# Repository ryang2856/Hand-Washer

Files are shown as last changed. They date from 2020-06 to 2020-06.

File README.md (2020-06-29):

# Hand-Washer
The ESP8266 powered tutorial with a display to teach you how to wash your hands<br />	
Please check out my Arduino Project here: https://create.arduino.cc/projecthub/ryang2856/hand-washer-ed9280 <br />
<br />
The file structure is like this:
- 3D Printing Files {3D Printing STL files }
- Board Design (EasyEDA) {Easy EDA Source File with the GERBER.zip file}
- Code_NoClock {The code for the handwasher with NO clock}
- Code_Clock {The code for the handwasher with a clock}
- Schematic {The breadboard and PCB schematic in PDF Format}

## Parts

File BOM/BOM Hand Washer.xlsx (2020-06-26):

BOM Hand Washer
Merchant | Item | Cost | Website | Quantity
JLC PCB | Printed Circuit Boards | £3.24 | JLC PCB (https://jlcpcb.com/) | 5
Make It Quick LTD. | 3D Printed Front | £15.75 | Make It Quick (https://www.makeitquick.co.uk/) | 1
Make It Quick LTD. | 3D Printed Back | £8.30 | Make It Quick (https://www.makeitquick.co.uk/) | 1
Banggood | Display | £6.32 | Banggood Display (https://www.banggood.com/CP2102-ESP-12E-NodeMCU-Lua-WiFi-Test-Board-Development-Board-Based-on-ESP8266-WiFi-Module-p-1509282.html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) | 1
Banggood | HC-SR04 | £1.13 | Banggood Sensor (https://www.banggood.com/Wholesale-Geekcreit-Ultrasonic-Module-HC-SR04-Distance-Measuring-Ranging-Transducers-Sensor-DC-5V-2-450cm-p-40313.html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) | 1
Banggood | Wires | £1.49 | Banggood Wires (https://www.banggood.com/40pcs-10cm-Male-To-Female-Jumper-Cable-Dupont-Wire-For-Arduino-p-994063.html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) | 1 (40 Pack)
Banggood | Female Header Pins | £1.74 | Banggood Female Headers (https://www.banggood.com/10pcs-40Pin-2_54mm-Female-Header-Jumper-Connectors-Socket-For-DIY-p-945516.html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) | 1
 | Total: | £37.97
NB. Actual Costs will be much less due to the availability of a 3D Printer ( - ~£20) and bulk ordering PCB's

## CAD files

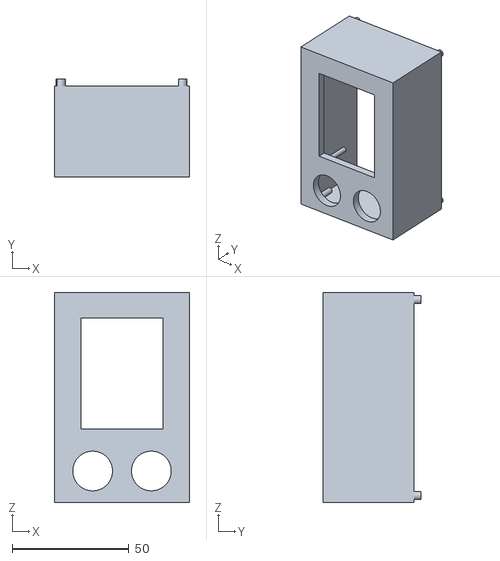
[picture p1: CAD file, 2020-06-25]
3D Printing Files/Main Part.stl
58.0 x 42.0 x 90.0

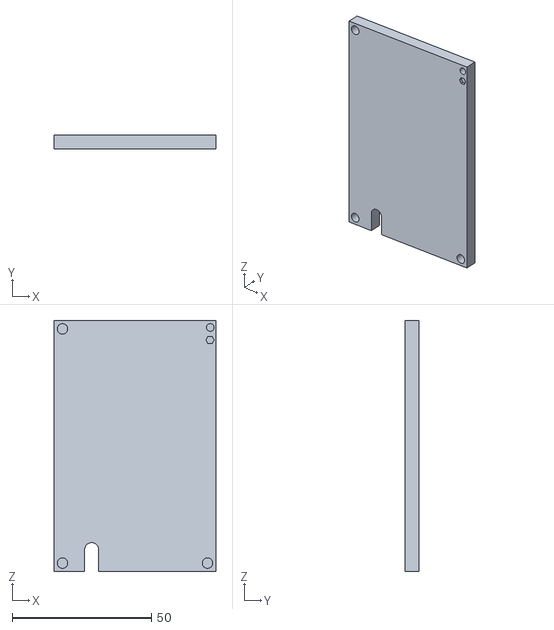
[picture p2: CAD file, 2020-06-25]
3D Printing Files/Bottom Part.stl
58.0 x 5.00 x 90.0

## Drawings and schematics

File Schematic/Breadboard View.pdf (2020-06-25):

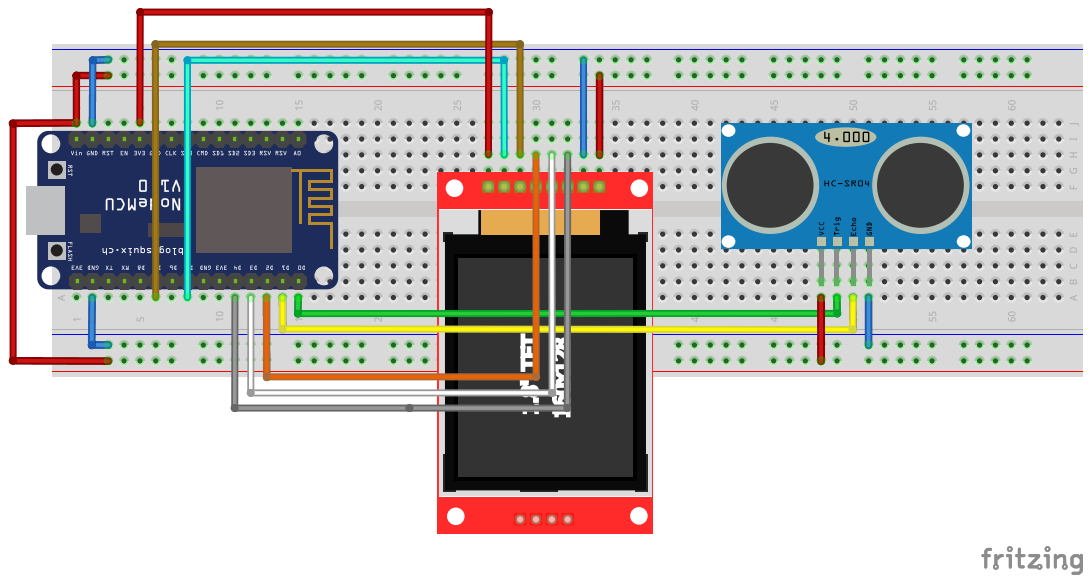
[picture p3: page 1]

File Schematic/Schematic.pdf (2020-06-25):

## NodeMCU

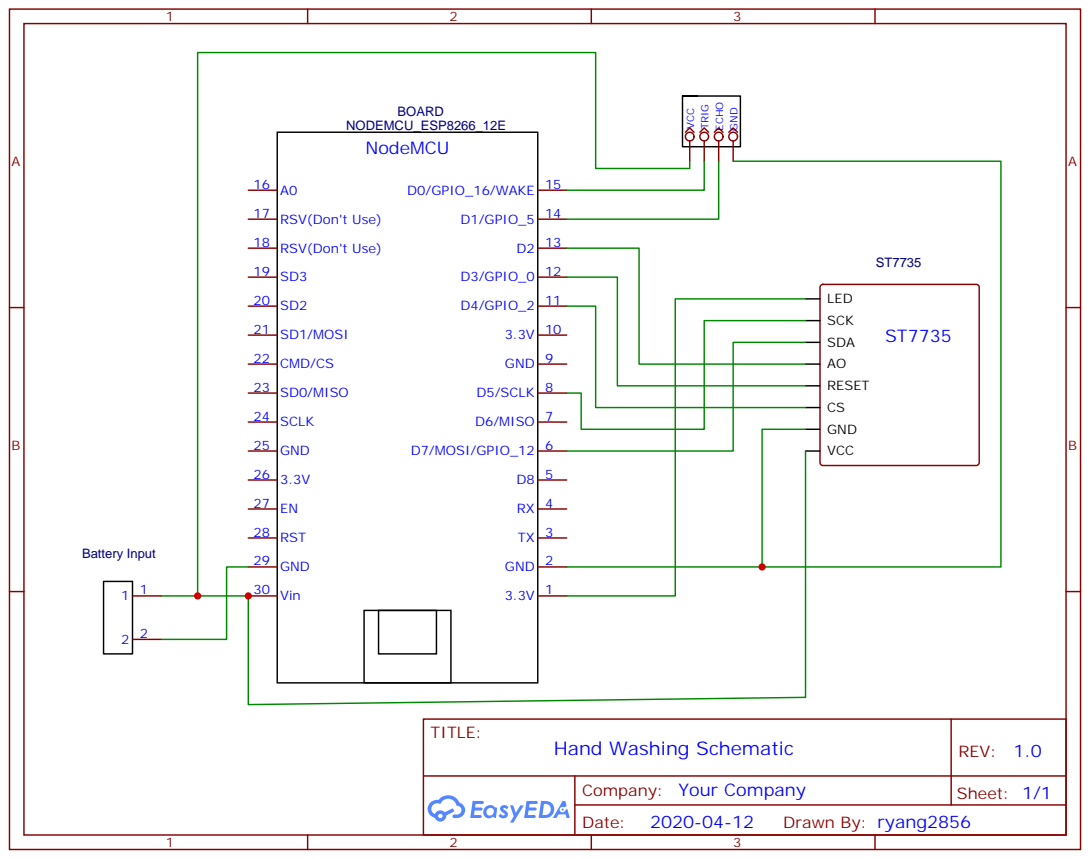
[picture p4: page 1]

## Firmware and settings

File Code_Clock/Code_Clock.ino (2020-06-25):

/*
   An open source project showing people how to wash their hands with a colour display
   Please refer to the project inorder to get more details
   REQUIRED LIBRARIES:
    Adafruit GFX
    Adafruit ST7735
    simpleDSTadjust
*/

#include <time.h>
#include <ESPWiFi.h>
#include <simpleDSTadjust.h>
#include <Ticker.h>
#include <Adafruit_GFX.h>    // include the Adafruit GFX Library
#include <Adafruit_ST7735.h> // include the Adafruit Library for driving this specific SPI display
#include <SPI.h> // include the SPI library as we communicate with the display using SPI

#define TFT_CS D4
#define TFT_RST D3 //Declaring pins
#define TFT_DC  D2

Adafruit_ST7735 tft = Adafruit_ST7735(TFT_CS, TFT_DC, TFT_RST); // init. the object tft

int triggerDistance = 40;  //CHANGE THIS FOR HOW CLOSE A HAND MUST BE TO START THE PROGRAM

const char* ssid = "";  //CHANGE THIS TO YOUR WIFI DETAILS
const char* password = ""; //CHANGE THIS TO YOUR WIFI DETIALS

const int trigPin = D0; //Declaring pins for the sensor
const int echoPin = D1;

bool triggered = false; //check if the sensors value has got smaller than the trigger distance

long duration; // measure how long it took for both the signal to be sent and then come back
int distanceCm; //the current distance being measurement

int runonce = 0;

extern  unsigned char  menuPage[];
extern  unsigned char  picture1[];
extern  unsigned char  picture2[];
extern  unsigned char  picture3[];
extern  unsigned char  picture4[];   //all the images
extern  unsigned char  picture5[];
extern  unsigned char  picture6[];
extern  unsigned char  picture7[];
extern  unsigned char  picture8[];


bool readyForNtpUpdate = false;
#define timezone +0    //timezone your own eg. -8

#define NTP_UPDATE_INTERVAL_SEC 5*3600

char *dstAbbrev;

struct dstRule StartRule = {"BST", Last, Sun, Mar, 2, 3600}; //Change this to your DST 
struct dstRule EndRule = {"GMT", Last, Sun, Oct, 2, 0};

#define NTP_SERVERS "0.ch.pool.ntp.org", "1.ch.pool.ntp.org", "2.ch.pool.ntp.org" //all the NTP servers
simpleDSTadjust dstAdjusted(StartRule, EndRule); //

Ticker ticker1; //create a ticker
int tick;

char new_time_str[11];  //variables used to check whether a new time is available
char old_time_str[11];

void setup()
{
  startup(); //setting up the display and sensor
  startTime_WiFi(); //start up the wifi and init the time ticker
  menu(); //displays menu
}

void loop()
{
  if (triggered == false) //if it isn't triggered
  {
    checkformovement(); //keep checking whether the sensor has detected someone
    if(String(new_time_str)!=String(old_time_str)) //keep checking whether there is a new time
    {
    tft.fillRect(20,40,128,20,ST77XX_BLACK);
    tft.setCursor(20, 40);                                //update the time
    tft.println(String(new_time_str));
    memcpy(old_time_str,new_time_str,strlen(new_time_str)); //copy the array contents into the old variable for checking later
    }
  }
  else
  {
    runSteps(); //if it did get triggered run the steps
  }

}

void startTime_WiFi()
{
  tft.setCursor(3, 10);
  tft.setTextSize(2);
  tft.println("Connecting");
  tft.setCursor(40, 40);   //connect to wifi
  tft.println("WiFi");
  WiFi.begin(ssid, password);
  Serial.println("\nConnecting");
  while (WiFi.status() != WL_CONNECTED)
  {
    delay(500);
    Serial.print("*");
  }
  timeSetup();
  tft.fillScreen(ST77XX_BLACK); //screen black
}
void runSteps()
{
  step1(); //step1
  step2(); //step2
  step3(); //step3
  step4(); //step4
  step5(); //step5
  step6(); //step6
  step7(); //step7
  step8(); //step8
  clearscreen(8); //clear the screen
  menu(); //display the menu
  resetvariables(); //reset the variable
}

void startup()
{
  Serial.begin(9600);
  tft.initR(INITR_BLACKTAB); //start display
  tft.fillScreen(ST77XX_BLACK); //make it black
  tft.setTextWrap(false);
  tft.setRotation(2);
  pinMode(trigPin, OUTPUT); //init. inputs / outputs
  pinMode(echoPin, INPUT);
}

void menu()
{
  tft.drawBitmap(00, 00, menuPage, 128, 160, ST77XX_WHITE); //waiting for motion to be detected
  tft.drawLine(0, 65, 128, 65, ST77XX_BLUE); //draw the menu
}

void checkformovement()
{
  digitalWrite(trigPin, LOW); //turns off the wave
  delayMicroseconds(2);
  digitalWrite(trigPin, HIGH); // turns on the wave
  delayMicroseconds(10);
  digitalWrite(trigPin, LOW);  //turns off the wave to be read
  duration = pulseIn(echoPin, HIGH); //measure the time it took to bounce back
  distanceCm = duration * 0.034 / 2; // works out the cm by taking the duration multiplying it by 0.034
  // which gives the length of both the wave going towards and coming
  //back so we divide it by 2
  if (triggerDistance > distanceCm)
  {
    triggered = true;
  }
}

void clearscreen(int i)
{
  if (runonce == i)
  {
    tft.fillScreen(ST77XX_BLACK);
    runonce += 1;
  }
}

void resetvariables()
{
  triggered = false;
  runonce = 0;
}

void counter(int time_start, int x, int y)
{
  for (int i = time_start; i != 0; i = i - 1)
  {
    tft.setCursor(x, y);
    tft.setTextSize(2);
    tft.println(i);
    delay(1000);
    tft.fillRect(x, y, 20, 15, ST77XX_BLACK);
  }
}


void step1()
{
  tft.setTextColor(ST77XX_GREEN);
  clearscreen(0);
  tft.fillRect(0, 45, 128, 3, ST77XX_BLUE);
  tft.drawBitmap(00, 00, picture1, 128, 160, ST77XX_WHITE);
  counter(5, 80, 25);
}

void step2()
{
  clearscreen(1);
  tft.fillRect(0, 40, 128, 3, ST77XX_BLUE);
  tft.drawBitmap(00, 00, picture2, 128, 160, ST77XX_WHITE);
  counter(5, 80, 20);
}

void step3()
{
  clearscreen(2);
  tft.fillRect(0, 37, 128, 3, ST77XX_BLUE);
  tft.drawBitmap(00, 00, picture3, 128, 160, ST77XX_WHITE);
  counter(5, 85, 18);
}

void step4()
{
  clearscreen(3);
  tft.fillRect(0, 45, 128, 3, ST77XX_BLUE);
  tft.drawBitmap(00, 00, picture4, 128, 160, ST77XX_WHITE);
  counter(5, 95, 22);
}

void step5()
{
  clearscreen(4);
  tft.fillRect(0, 63, 128, 3, ST77XX_BLUE);
  tft.drawBitmap(00, 00, picture5, 128, 160, ST77XX_WHITE);
  counter(5, 105, 33);
}

void step6()
{
  clearscreen(5);
  tft.fillRect(0, 40, 128, 1, ST77XX_BLUE);
  tft.drawBitmap(00, 00, picture6, 128, 160, ST77XX_WHITE);
  counter(5, 90, 19);
}

void step7()
{
  clearscreen(6);
  tft.fillRect(0, 59, 128, 3, ST77XX_BLUE);
  tft.drawBitmap(00, 00, picture7, 128, 160, ST77XX_WHITE);
  counter(5, 85, 27);
}

void step8()
{
  clearscreen(7);
  tft.fillRect(0, 65, 128, 3, ST77XX_BLUE);
  tft.drawBitmap(00, 00, picture8, 128, 160, ST77XX_WHITE);
  counter(5, 90, 12);
}

void timeSetup()
{
  updateNTP();
  printTime(0);

  tick = NTP_UPDATE_INTERVAL_SEC;
  ticker1.attach(1, sendTime);
}

void updateNTP() {

  configTime(timezone * 3600, 0, NTP_SERVERS);

  delay(500);
  while (!time(nullptr)) {
    delay(1000);
  }
}
void printTime(time_t offset) {
  time_t t = dstAdjusted.time(&dstAbbrev);
  struct tm * timeinfo = localtime (&t);
  sprintf(new_time_str, "%02d:%02d:%02d\n", timeinfo->tm_hour, timeinfo->tm_min, timeinfo->tm_sec);
  Serial.println(new_time_str);
  checkTimeUpdate();
}
void checkTimeUpdate()
{
  if (readyForNtpUpdate)
  {
    readyForNtpUpdate = false;
    updateNTP();
  }
}
void sendTime()
{
  tick--;
  if (tick <= 0)
  {
    readyForNtpUpdate = true;
    tick = NTP_UPDATE_INTERVAL_SEC;
  }

  printTime(0);
}
